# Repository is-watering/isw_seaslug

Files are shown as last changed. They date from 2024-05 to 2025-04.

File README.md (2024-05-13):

# ISW-SEASLUG
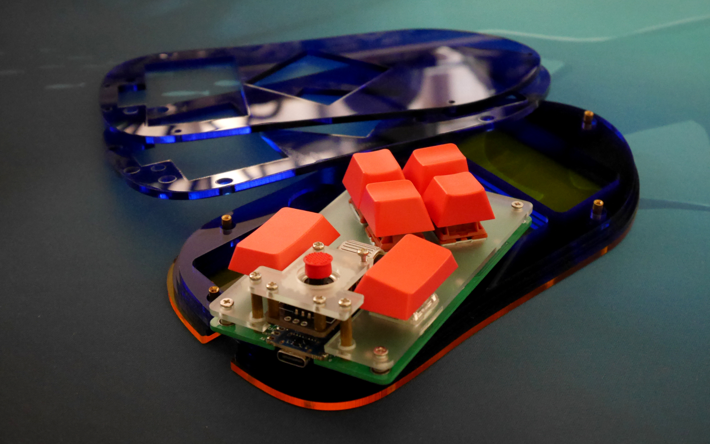
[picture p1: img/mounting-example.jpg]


ISW-SEASLUG is designed for use in combination with a trackball or joystick.

[Build guide](doc/buildguide.md)

## Dependencies (KiCad)
* [is-watering/isw-kbd-lib](https://github.com/is-watering/isw-kbd-lib)
* [Salicylic-acid3/KiCAD_FootPrint](https://github.com/Salicylic-acid3/KiCAD_FootPrint)
* [koktoh/BrownSugar_KBD_KiCad_Library](https://github.com/koktoh/BrownSugar_KBD_KiCad_Library)

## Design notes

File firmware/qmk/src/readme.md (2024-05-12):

# isw_seaslug

isw_seaslug

*A short description of the keyboard/project*

* Keyboard Maintainer: [is-watering](https://github.com/is-watering)
* Hardware Supported: *The PCBs, controllers supported*
* Hardware Availability: *Links to where you can find this hardware*

Make example for this keyboard (after setting up your build environment):

    make isw_seaslug:default

Flashing example for this keyboard:

    make isw_seaslug:default:flash

See the [build environment setup](https://docs.qmk.fm/#/getting_started_build_tools) and the [make instructions](https://docs.qmk.fm/#/getting_started_make_guide) for more information. Brand new to QMK? Start with our [Complete Newbs Guide](https://docs.qmk.fm/#/newbs).

## Bootloader

Enter the bootloader in 3 ways:

* **Bootmagic reset**: Hold down the key at (0,0) in the matrix (usually the top left key or Escape) and plug in the keyboard
* **Physical reset button**: Briefly press the button on the back of the PCB - some may have pads you must short instead
* **Keycode in layout**: Press the key mapped to `QK_BOOT` if it is available

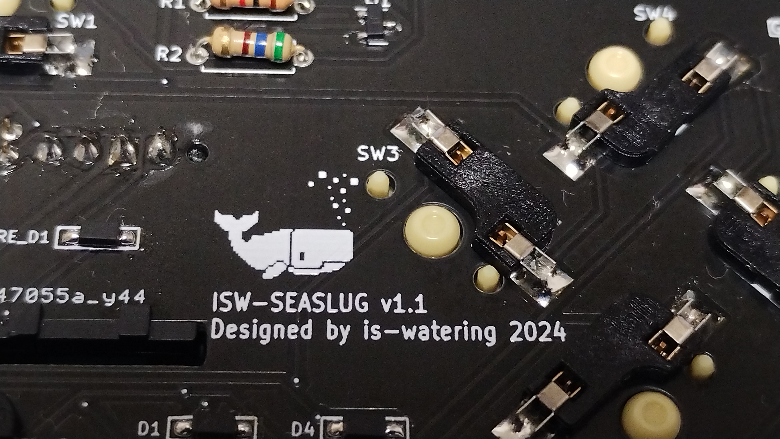
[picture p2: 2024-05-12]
firmware/qmk/evidence/evidence.jpg

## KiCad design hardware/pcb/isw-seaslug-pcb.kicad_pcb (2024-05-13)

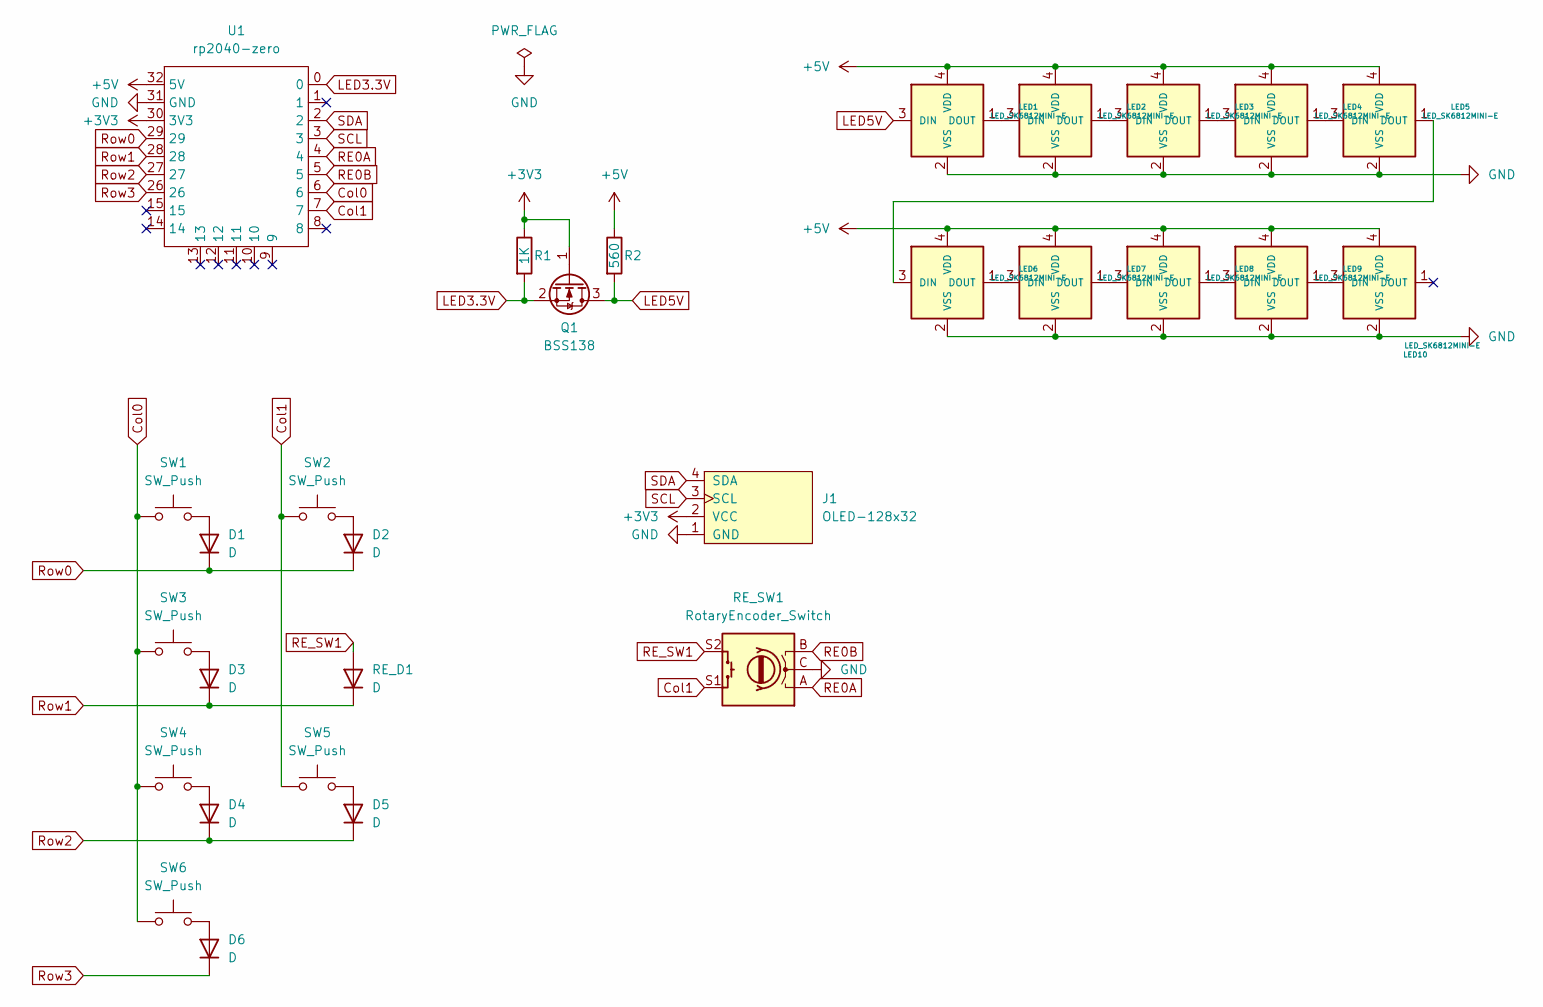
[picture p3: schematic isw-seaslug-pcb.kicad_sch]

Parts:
D1, D2, D3, D4, D5, D6: D; Diode_SMD
J1: OLED-128x32; StickPointV
LED1, LED2, LED3, LED4, LED5, LED6, LED7, LED8, LED9, LED10: LED_SK6812MINI-E; LED_SK6812MINI-E_UG
Q1: BSS138; SOT-23
R1, R2: R; R_Axial_DIN0207_L6.3mm_D2.5mm_P7.62mm_Horizontal
RE_D1: D; Diode_SMD
RE_SW1: RotaryEncoder_Switch; RotaryEncoder_EVQWGD001
SW1, SW2, SW3, SW4, SW5, SW6: SW_Push; CherryMX_Hotswap_1u
U1: rp2040-zero; RP2040-Zero-THT

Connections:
+3V3: J1.2 (VCC), Q1.1 (G), R1.1, U1.30 (3V3)
+5V: LED1.4 (VDD), LED2.4 (VDD), LED3.4 (VDD), LED4.4 (VDD), LED5.4 (VDD), LED6.4 (VDD), LED7.4 (VDD), LED8.4 (VDD), LED9.4 (VDD), LED10.4 (VDD), R2.1, U1.32 (5V)
Col0: SW1.1, SW3.1, SW4.1, SW6.1, U1.6
Col1: RE_SW1.S1, SW2.1, SW5.1, U1.7
GND: J1.1 (GND), LED1.2 (VSS), LED2.2 (VSS), LED3.2 (VSS), LED4.2 (VSS), LED5.2 (VSS), LED6.2 (VSS), LED7.2 (VSS), LED8.2 (VSS), LED9.2 (VSS), LED10.2 (VSS), RE_SW1.C, U1.31 (GND)
LED3.3V: Q1.2 (S), R1.2, U1.0
LED5V: LED1.3 (DIN), Q1.3 (D), R2.2
unnamed: D1.2 (A), SW1.2
unnamed: D2.2 (A), SW2.2
unnamed: D3.2 (A), SW3.2
unnamed: D4.2 (A), SW4.2
unnamed: D5.2 (A), SW5.2
unnamed: D6.2 (A), SW6.2
unnamed: LED1.1 (DOUT), LED2.3 (DIN)
unnamed: LED2.1 (DOUT), LED3.3 (DIN)
unnamed: LED3.1 (DOUT), LED4.3 (DIN)
unnamed: LED4.1 (DOUT), LED5.3 (DIN)
unnamed: LED5.1 (DOUT), LED6.3 (DIN)
unnamed: LED6.1 (DOUT), LED7.3 (DIN)
unnamed: LED7.1 (DOUT), LED8.3 (DIN)
unnamed: LED8.1 (DOUT), LED9.3 (DIN)
unnamed: LED9.1 (DOUT), LED10.3 (DIN)
RE0A: RE_SW1.A, U1.4
RE0B: RE_SW1.B, U1.5
RE_SW1: RE_D1.2 (A), RE_SW1.S2
Row0: D1.1 (K), D2.1 (K), U1.29
Row1: D3.1 (K), RE_D1.1 (K), U1.28
Row2: D4.1 (K), D5.1 (K), U1.27
Row3: D6.1 (K), U1.26
SCL: J1.3 (SCL), U1.3
SDA: J1.4 (SDA), U1.2

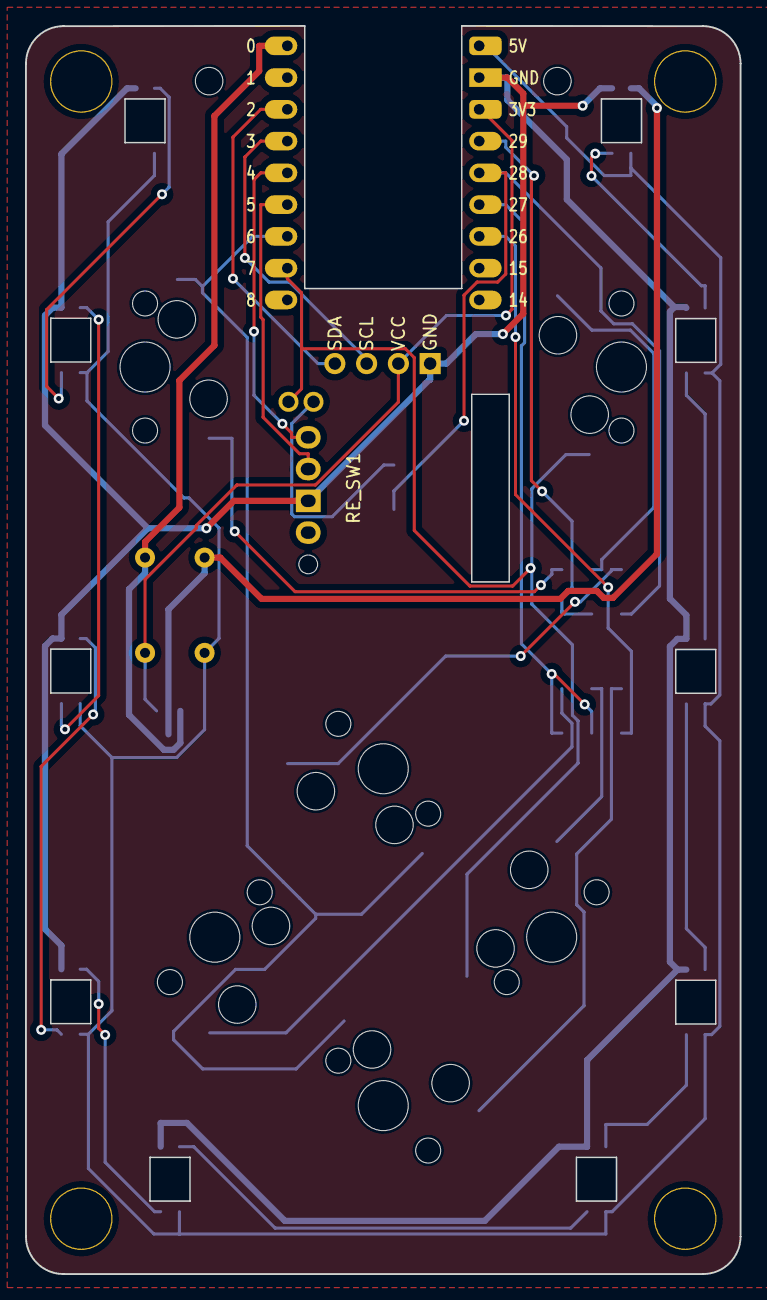
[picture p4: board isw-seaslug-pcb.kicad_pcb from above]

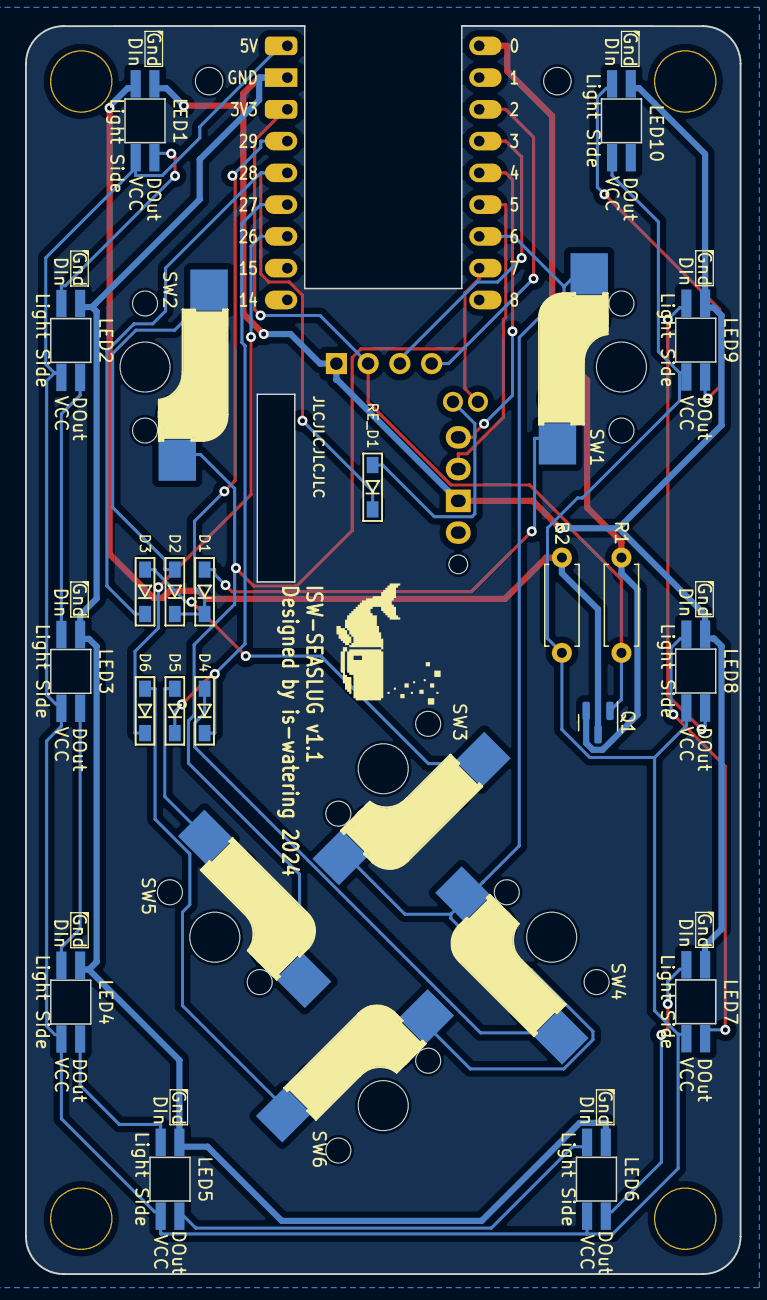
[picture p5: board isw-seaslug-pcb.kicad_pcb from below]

Board: 2 copper layers, 57.1 x 99.8 mm, 35 parts (4 on the bottom side), 31 nets.

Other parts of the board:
Ref01, Ref02, Ref03, Ref04: Val01; m2_Spacer_Hole
Ref11, Ref12: Val02; m2_Screw_Hole

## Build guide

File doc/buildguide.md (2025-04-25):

# Build guide

## Parts
Name                     |Quantity |Notes
-------------------------|---------|-----
PCB                      |1        |[Here's the data](https://github.com/is-watering/isw_seaslug/tree/main/hardware/pcb)|
Switch plate             |1        | |
Bottom plate             |1        | |
Cover plate              |1        | |
1N4148W diodes           |6        | |
SK6812 MINI-E leds       |10       | |
MOSFET BSS138            |1        | |
1kΩ resistor             |1        | |
560Ω resistor            |1        | |
Kailh hotswap sockets    |6        | |
RP2040-Zero              |1        | |
M2x4mm screws            |12        | |
M2x7mm spacers           |4        |[HIROSUGI NET](https://www.hirosugi-net.co.jp/shop/c/c10141012/)|
M2x12mm Knurled spacers   |2        |[Aliexpress](https://www.aliexpress.com/item/1005002979083511.html)|

### Optionally
Name |Quantity |Notes
-----|---------|-----
EVQWGD001 rotary encoder  |1    |[Aliexpress](https://www.aliexpress.com/item/32990950196.html), [TALPKEYBOARD](https://talpkeyboard.net/items/65cdb71207d2c4002b622ce0), [Yushakobo](https://shop.yushakobo.jp/products/3971)|
1N4148W diodes            |1    |Used when EVQWGD001 is installed|
AZ1UBALL                  |1    |Only one of this or StickPointV can be attached.<br>[Booth](https://booth.pm/ja/items/4202085)|
StickPointV               |1    |Only one of this or AZ1UBALL can be attached.<br>Also, use those without glove socket mounts.<br>[Booth](https://booth.pm/ja/items/5404009)|
FSS-41035-04 4P pinsocket |1    |Used when AZ1UBALL or StickPointV is installed.<br>[HIROSUGI NET](https://www.hirosugi-net.co.jp/shop/goods/goods.aspx?goods=24081), [Yushakobo](https://shop.yushakobo.jp/products/a1600ps-01-1)|
PSS-410153-04 4P pinheader |1    |Used when AZ1UBALL or StickPointV is installed.<br>[HIROSUGI NET](https://www.hirosugi-net.co.jp/shop/g/g21243/), [Yushakobo](https://shop.yushakobo.jp/products/a1600ph-01-1)|
M2x6mm Knurled spacers     |4        |Used when StickPointV is installed.<br>[Aliexpress](https://www.aliexpress.com/item/1005002979083511.html)|
M2x14mm Knurled spacers    |4        |Used when StickPointV is installed.<br>[Aliexpress](https://www.aliexpress.com/item/1005002979083511.html)|

## Build PCB

### [Leds](https://github.com/is-watering/isw-kbd-building-tips/blob/main/doc/en/soldering-sk6812mini-e.md)

### [Diodes](https://github.com/is-watering/isw-kbd-building-tips/blob/main/doc/en/soldering-1n4148w.md)

### [MOSFET](https://github.com/is-watering/isw-kbd-building-tips/blob/main/doc/en/soldering-bss138.md)

### [Resistors](https://github.com/is-watering/isw-kbd-building-tips/blob/main/doc/en/soldering-resistor.md)
Solder a 1kΩ resistor to R1 and a 560Ω resistor to R2.  

### [Hotswap sockets](https://github.com/is-watering/isw-kbd-building-tips/blob/main/doc/en/soldering-cpg151101s11.md)

### RP2040-Zero
It is recommended to check whether the firmware can be written to the microcontroller in advance.
* [Remap](https://remap-keys.app/catalog/YQ8QgcHbuajsV3Ugj0US)
* [Soure code](https://github.com/is-watering/isw_seaslug/tree/main/firmware)

Solder the microcontroller from the top of the PCB, face down, using surface mount soldering.  
[Learn more about how to solder microcontrollers](https://github.com/is-watering/isw-kbd-building-tips/blob/main/doc/en/surfacemount-rp2040-zero.md)  
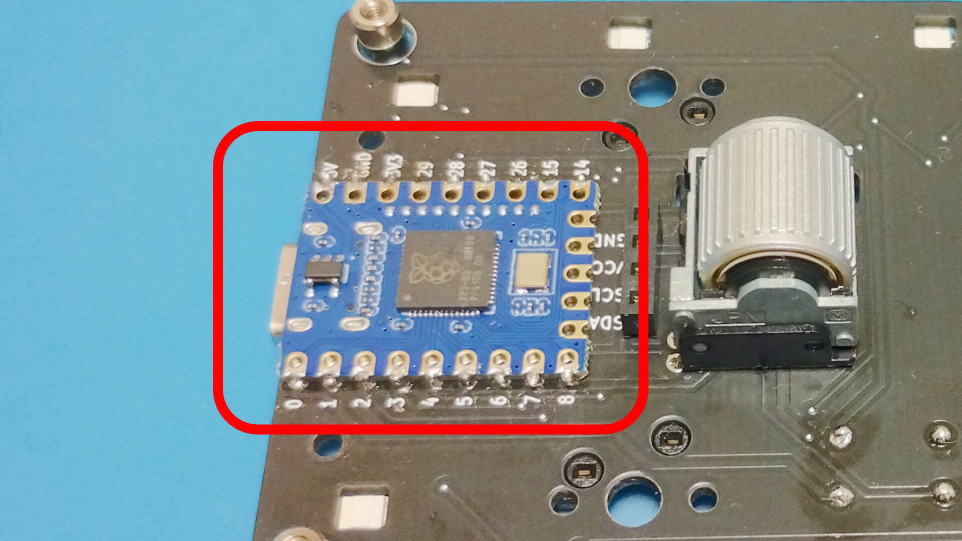
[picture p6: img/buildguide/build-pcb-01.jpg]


Fix 12mm Knurled spacers with 4mm screws.  
If StickPointV is to be installed, secure with 14mm Knurled spacers instead of 12mm.
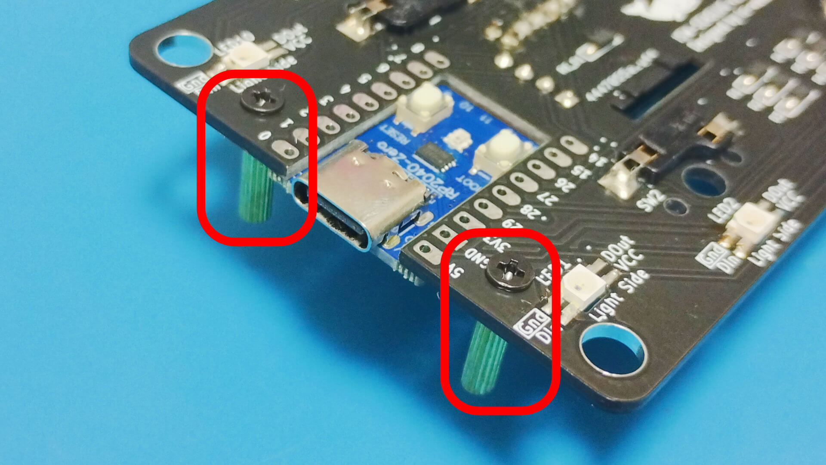
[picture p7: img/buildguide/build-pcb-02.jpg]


## Build Case
Use a 4mm screw to secure the 7mm spacer.  
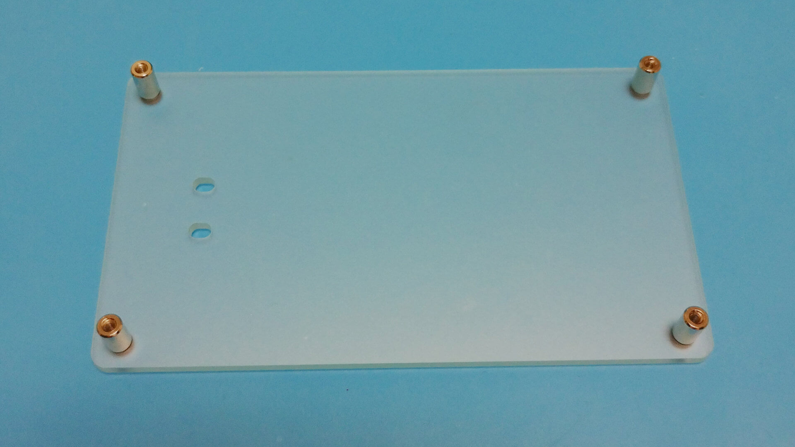
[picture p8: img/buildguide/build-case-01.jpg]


Place the PCB on the bottom plate.  
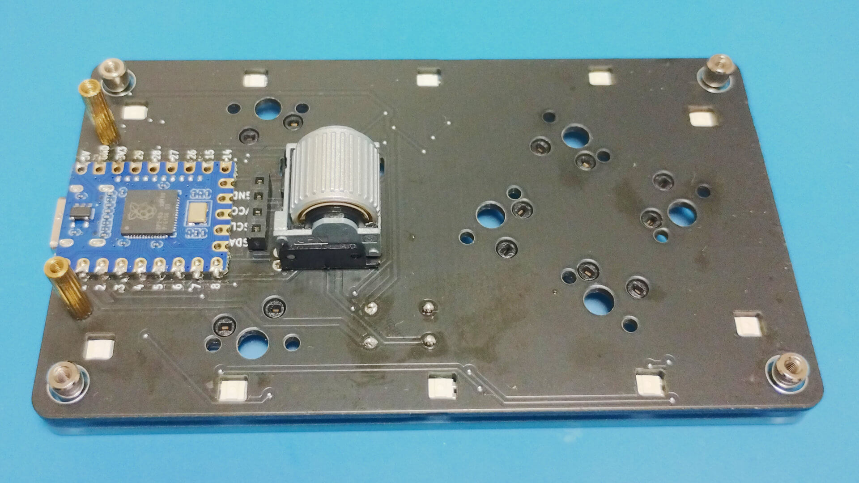
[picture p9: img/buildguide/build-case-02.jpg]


Place the switch plate on the PCB. It is easier to align key switches if they are mounted from the corners.  
Then fix the switch plate with 4mm screw.  
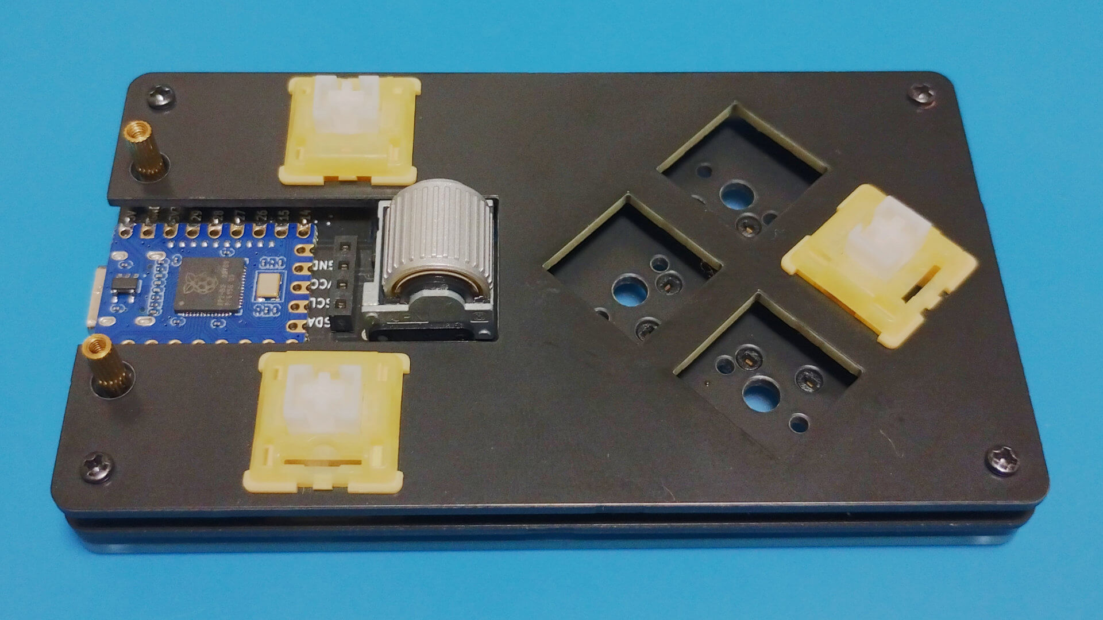
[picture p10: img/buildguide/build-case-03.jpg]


Install the remaining key switches and then screw the cover plate in place.  
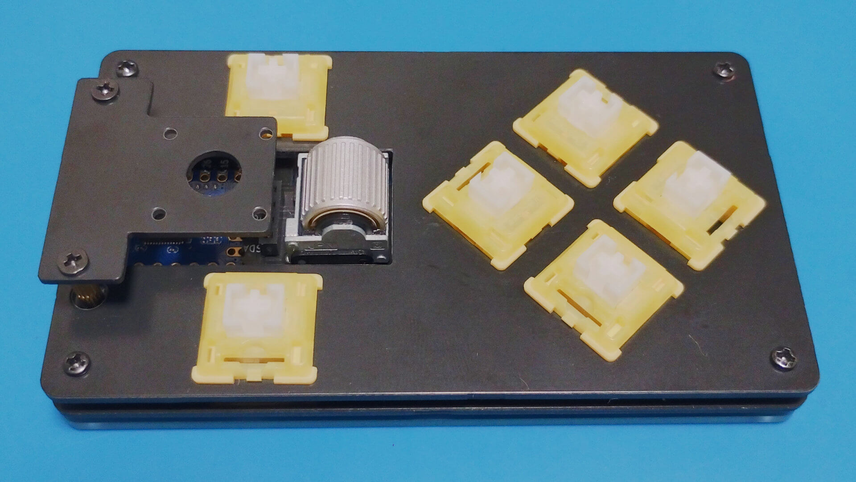
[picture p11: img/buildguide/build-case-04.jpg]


Attach a keycap of your choice to complete the process!  
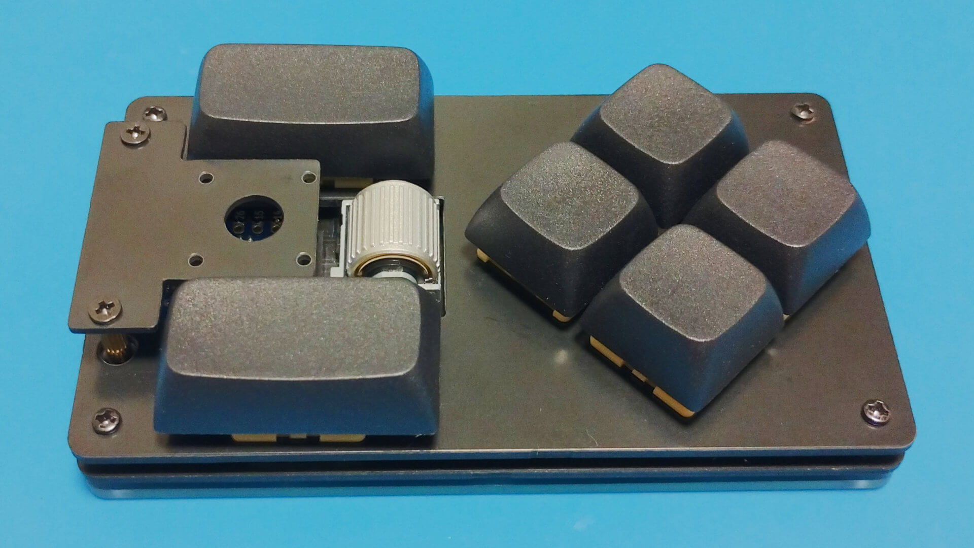
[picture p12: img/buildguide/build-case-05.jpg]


Congratulations on the completion!  
Please be proud of it on social networking sites!  
`#isw_kbd`

## Build Optionally
### [EVQWGD001 rotary encoder](https://github.com/is-watering/isw-kbd-building-tips/blob/main/doc/en/soldering-evqwgd001.md)

### AZ1UBALL or StickPointV
> [!IMPORTANT]
> When installing the StickPointV, replace the 12 mm knurled spacer fixed to the PCB with a 14 mm knurled spacer.

[Please solder the 4P pinsocket to the PCB in advance.](https://github.com/is-watering/isw-kbd-building-tips/blob/main/doc/en/soldering-4p-pinsocket.md)  
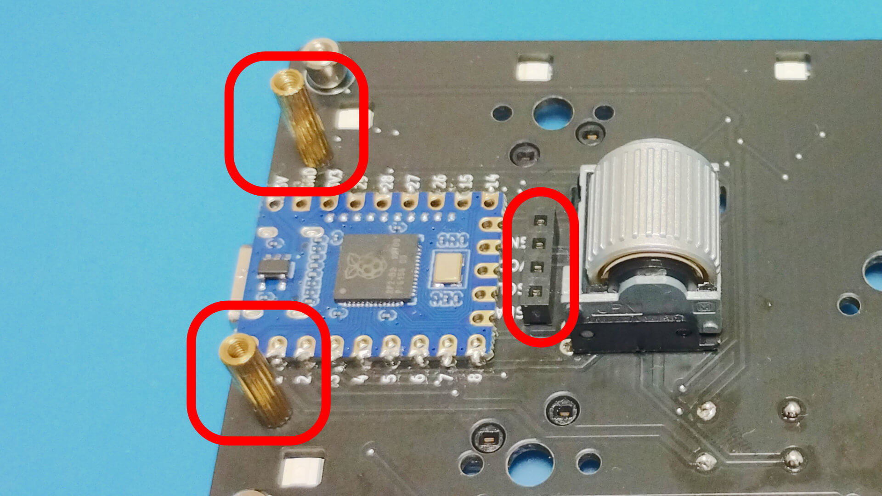
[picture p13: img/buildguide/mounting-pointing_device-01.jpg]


Secure the pointing device to the cover plate with 4 mm screws.  
> [!IMPORTANT]
> When installing the StickPointV, replace the spacer supplied with the StickPointV with a 6 mm knurled spacer.  
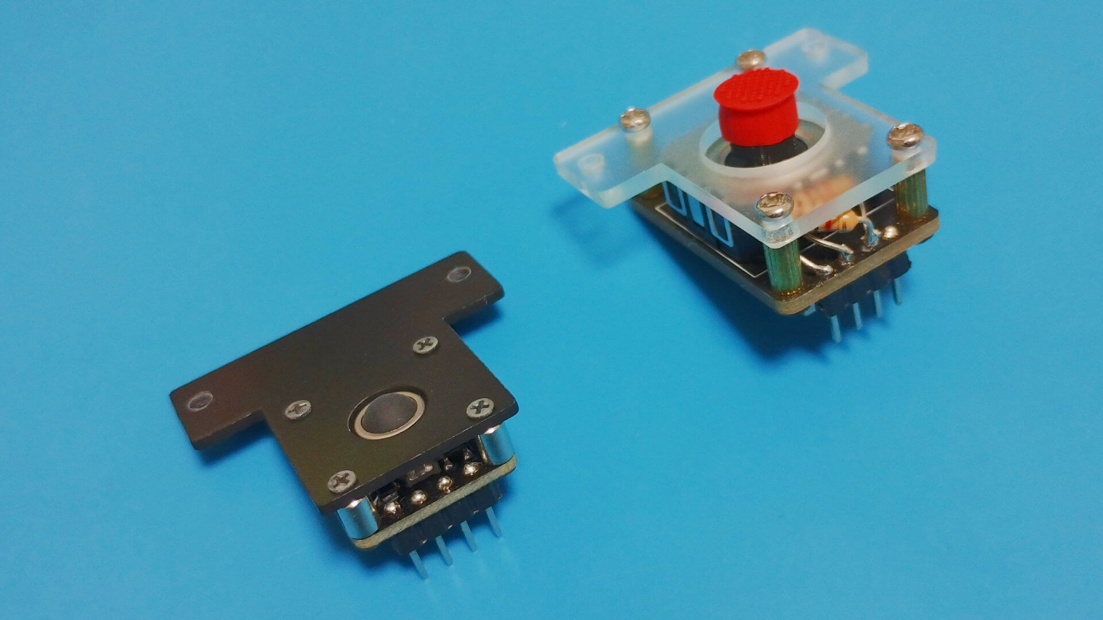
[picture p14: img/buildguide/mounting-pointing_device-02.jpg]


Plug the pointing device into the 4P pin socket.  
Then secure the cover plate with a 4 mm screws.  
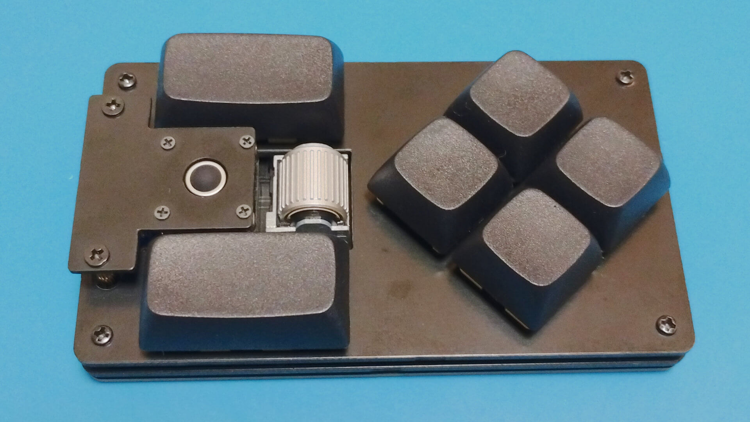
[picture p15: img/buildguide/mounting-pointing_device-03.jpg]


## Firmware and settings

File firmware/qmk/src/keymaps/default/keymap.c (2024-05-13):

/* SPDX-License-Identifier: GPL-2.0-or-later */

#include QMK_KEYBOARD_H

const uint16_t PROGMEM keymaps[][MATRIX_ROWS][MATRIX_COLS] = {

	[0] = LAYOUT(
		KC_BTN1,    KC_BTN2,
		KC_BTN3,
		KC_4,    KC_6,
		KC_5,    KC_7
	),

	[1] = LAYOUT(
		XXXXXXX, XXXXXXX,
		XXXXXXX,
		XXXXXXX, XXXXXXX,
		XXXXXXX, XXXXXXX
	),

	[2] = LAYOUT(
		XXXXXXX, XXXXXXX,
		XXXXXXX,
		XXXXXXX, XXXXXXX,
		XXXXXXX, XXXXXXX
	),

	[3] = LAYOUT(
		XXXXXXX, XXXXXXX,
		XXXXXXX,
		XXXXXXX, XXXXXXX,
		XXXXXXX, XXXXXXX
	),

};


/* `ENCODER_MAP_ENABLE = yes` must be added to the rules.mk at the KEYMAP level. See QMK docs. */
/* Remove the following code if you do not enable it in your keymap (e.g. default keymap). */
#if defined(ENCODER_MAP_ENABLE)
const uint16_t PROGMEM encoder_map[][NUM_ENCODERS][2] = {
	[0] = { ENCODER_CCW_CW(KC_WH_D, KC_WH_U) },
	[1] = { ENCODER_CCW_CW(RGB_VAD, RGB_VAI) },
	[2] = { ENCODER_CCW_CW(KC_NO, KC_NO) },
	[3] = { ENCODER_CCW_CW(KC_NO, KC_NO) }
};
#endif
